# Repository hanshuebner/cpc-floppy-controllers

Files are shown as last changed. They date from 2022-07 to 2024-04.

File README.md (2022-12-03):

# Amstrad/Schneider CPC floppy controllers

> :warning: **This is a work in progress**: Don't fabricate PCBs from these files yet!

This project started as attempt to clone the Vortex F1-D floppy
controller, which supports two 720k DSDD drives.  The desire was to
have a controller that can support four drives at the same time.  The
starting point was a capture of the original PCB into a schematic,
which can be found in the [original](original/) directory.

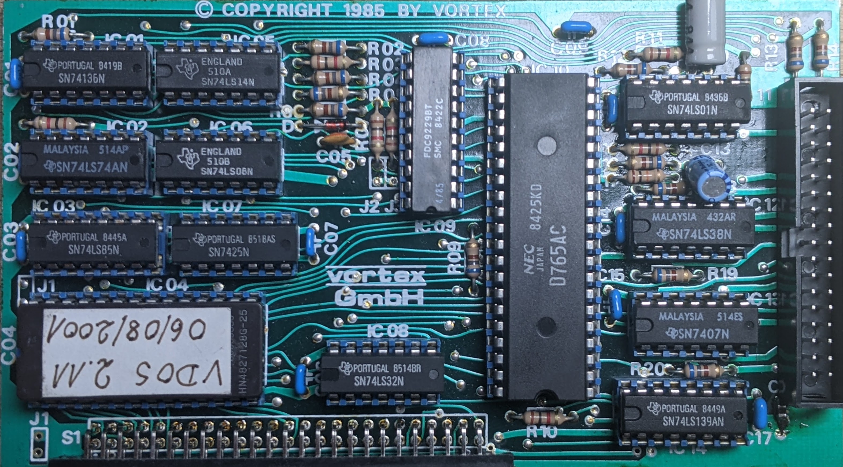
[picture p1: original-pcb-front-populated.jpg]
Vortex F1-D PCB


Multiple variants have been designed, but none of the designs in this
repository have been tested, don't fabricate any PCBs at this point!

# no-rom

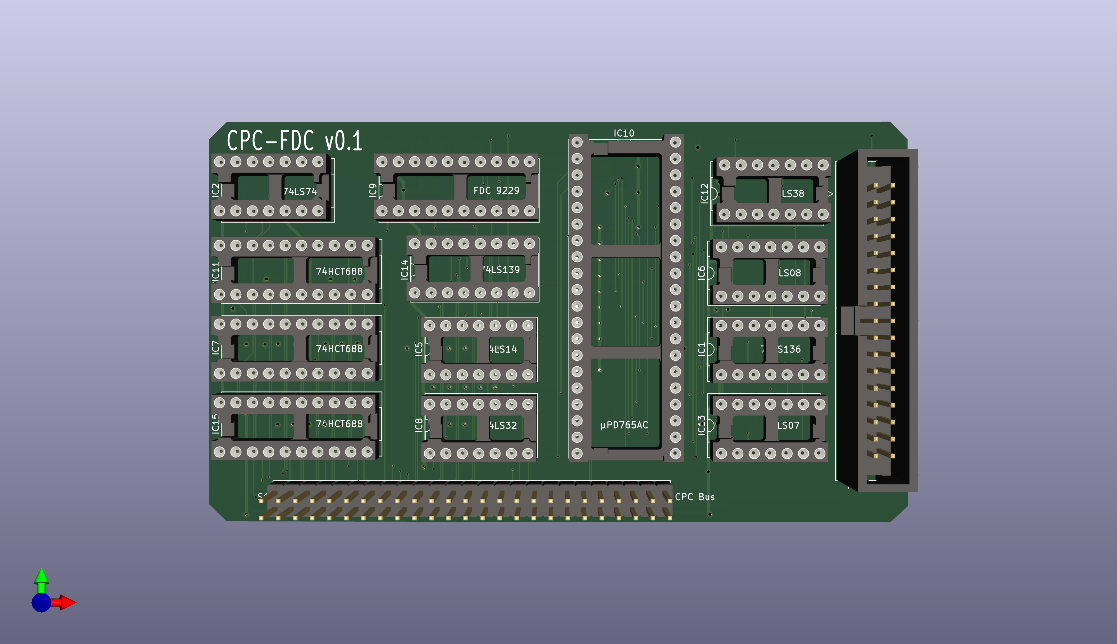
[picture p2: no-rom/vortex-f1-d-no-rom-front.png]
rendered picture of the no-rom PCB variant (front)

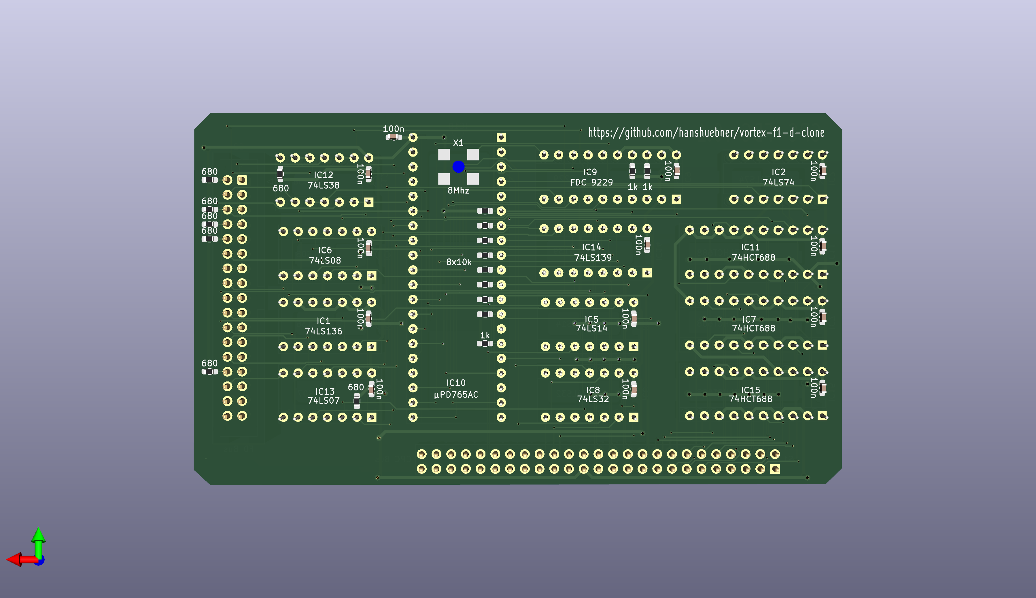
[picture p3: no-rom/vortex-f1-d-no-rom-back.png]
rendered picture of the no-rom PCB variant (back)


The [no-rom](no-rom/) variant contains a revised, but wasteful address
decoder and no ROM socket.  It works to some extent, but the first
revisions contained multiple errors and required several patches.  The
version in this repository has the fixes applied, but was not yet
fabricated and tested.

# no-rom-cpld

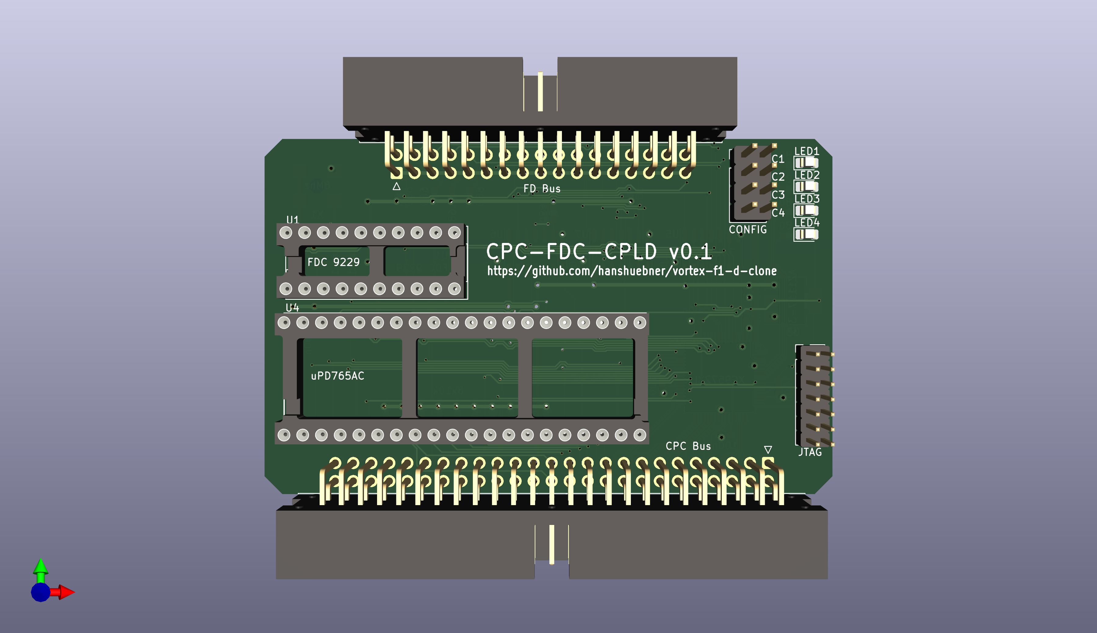
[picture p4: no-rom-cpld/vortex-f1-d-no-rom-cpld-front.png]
rendered picture of the no-rom-cpld variant (front)

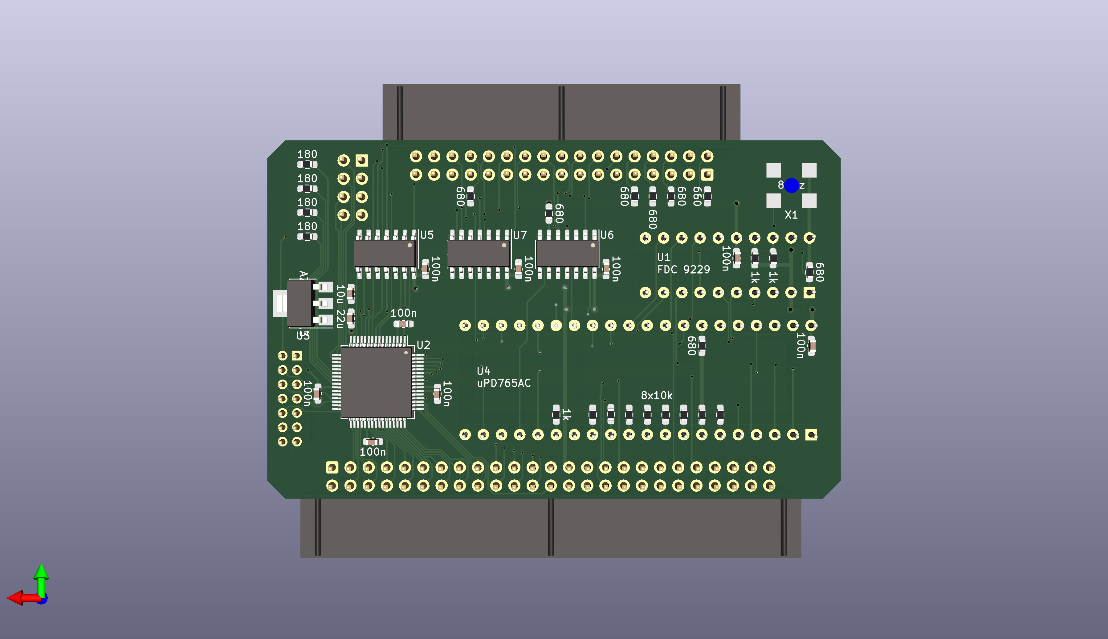
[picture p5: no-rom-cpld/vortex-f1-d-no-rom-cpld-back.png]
rendered picture of the no-rom-cpld variant (back)


The [no-rom-cpld](no-rom-cpld/) variant replaces the TTL chips with a
CPLD, reducing the part count significantly.

# rom-cpld

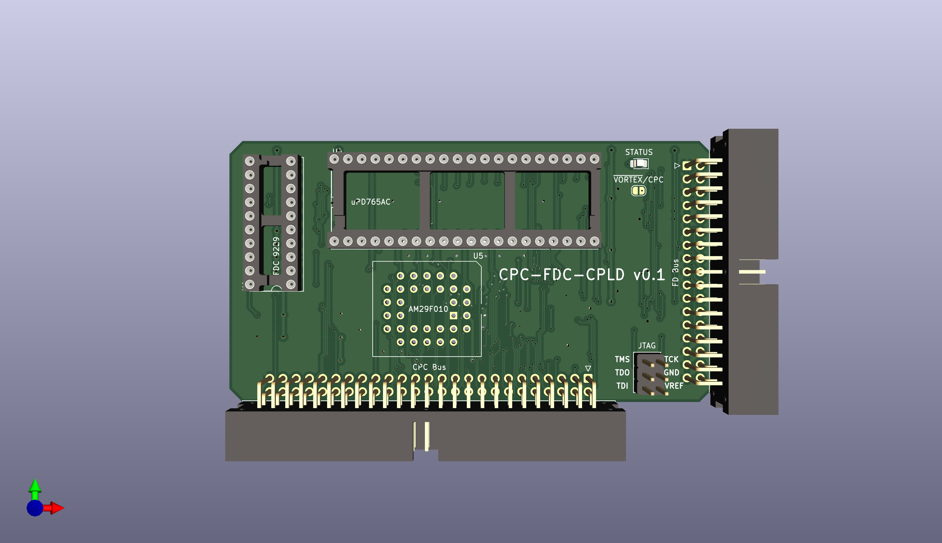
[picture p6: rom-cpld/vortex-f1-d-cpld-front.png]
rendered picture of the rom-cpld variant (front)

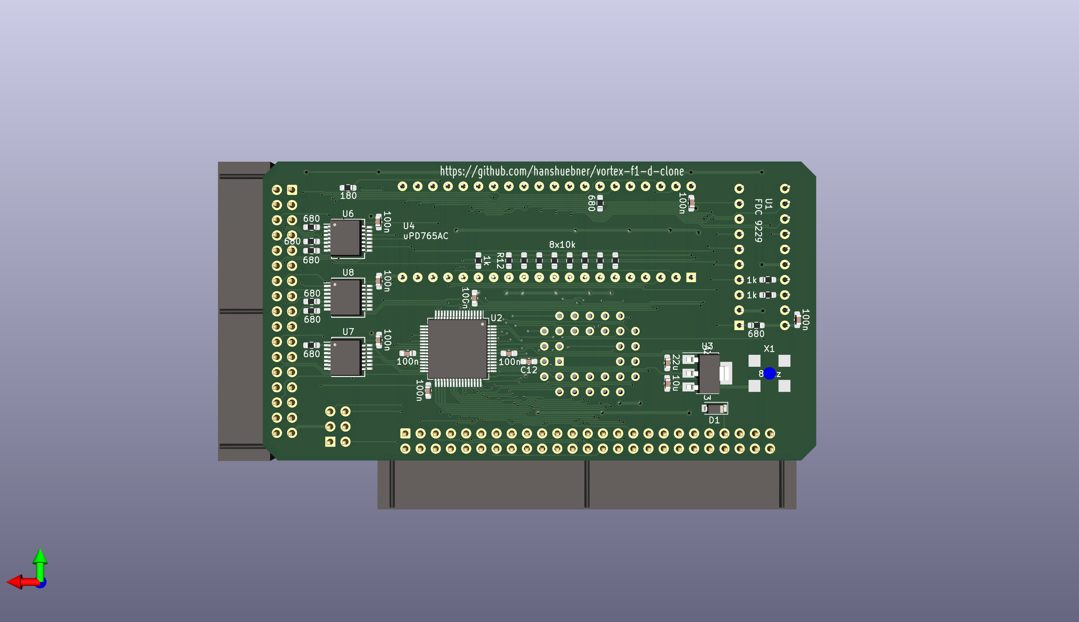
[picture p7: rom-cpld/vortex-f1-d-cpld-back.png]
rendered picture of the rom-cpld variant (back)


The [rom-cpld](rom-cpld/) variant adds a Flash ROM that can act as a universal
ROM box in addition to holding an operating system ROM to drive the
floppy disk controller.

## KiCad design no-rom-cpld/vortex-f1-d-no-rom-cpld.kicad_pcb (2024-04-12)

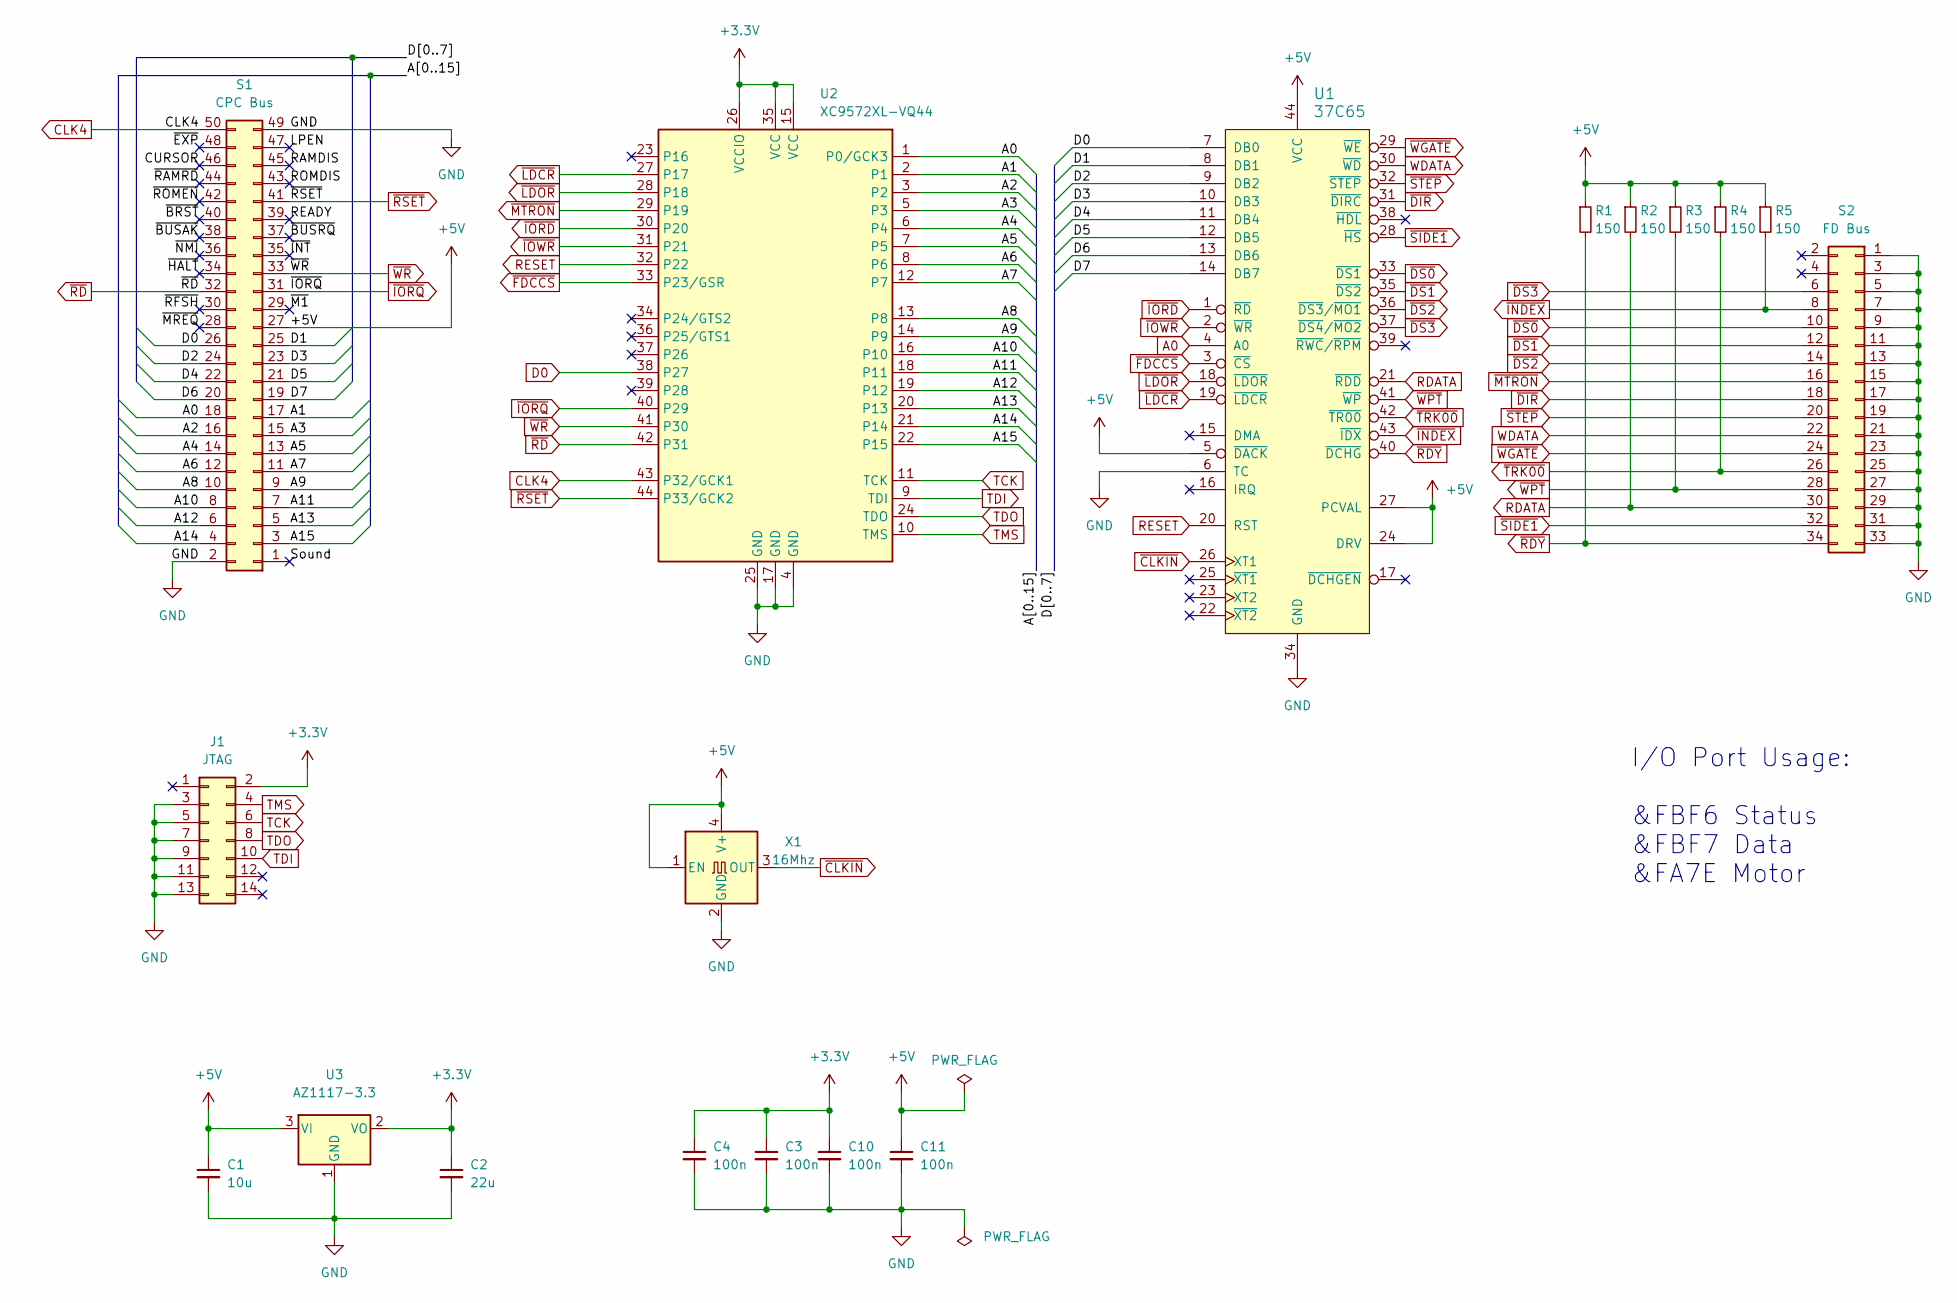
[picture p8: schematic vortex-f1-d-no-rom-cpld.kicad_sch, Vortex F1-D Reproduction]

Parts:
C1: 10u; C_0603_1608Metric_Pad1.08x0.95mm_HandSolder
C2: 22u; C_0603_1608Metric_Pad1.08x0.95mm_HandSolder
C3, C4, C10, C11: 100n; C_0603_1608Metric_Pad1.08x0.95mm_HandSolder
J1: JTAG; PinHeader_2x07_P2.00mm_Vertical
R1, R2, R3, R4, R5: 150; R_0603_1608Metric_Pad0.98x0.95mm_HandSolder
S1: CPC Bus; IDC-Header_2x25_P2.54mm_Horizontal
S2: FD Bus; IDC-Header_2x17_P2.54mm_Horizontal
U1: 37C65; PLCC-44
U2: XC9572XL-VQ44; TQFP-44_10x10mm_P0.8mm
U3: AZ1117-3.3; SOT-223-3_TabPin2
X1: 16Mhz; Oscillator_SMD_EuroQuartz_XO91-4Pin_7.0x5.0mm

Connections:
+3.3V: C2.1, C3.1, C4.1, C10.1, J1.2, U2.15 (VCC), U2.26 (VCCIO), U2.35 (VCC), U3.2 (VO)
+5V: C1.1, C11.1, R1.1, R2.1, R3.1, R4.1, R5.1, S1.27, U1.5 (~DACK), U1.24 (DRV), U1.27 (PCVAL), U1.44 (VCC), U3.3 (VI), X1.1 (EN), X1.4 (V+)
/A1: S1.17, U2.2 (P1)
/A2: S1.16, U2.3 (P2)
/A3: S1.15, U2.5 (P3)
/A4: S1.14, U2.6 (P4)
/A5: S1.13, U2.7 (P5)
/A6: S1.12, U2.8 (P6)
/A7: S1.11, U2.12 (P7)
/A8: S1.10, U2.13 (P8)
/A9: S1.9, U2.14 (P9)
/A10: S1.8, U2.16 (P10)
/A11: S1.7, U2.18 (P11)
/A12: S1.6, U2.19 (P12)
/A13: S1.5, U2.20 (P13)
/A14: S1.4, U2.21 (P14)
/A15: S1.3, U2.22 (P15)
/CURSOR: S1.46
/D1: S1.25, U1.8 (DB1)
/D2: S1.24, U1.9 (DB2)
/D3: S1.23, U1.10 (DB3)
/D4: S1.22, U1.11 (DB4)
/D5: S1.21, U1.12 (DB5)
/D6: S1.20, U1.13 (DB6)
/D7: S1.19, U1.14 (DB7)
/LPEN: S1.47
/RAMDIS: S1.45
/READY: S1.39
/ROMDIS: S1.43
/Sound: S1.1
/~BRST: S1.40
/~BUSAK: S1.38
/~BUSRQ: S1.37
/~EXP: S1.48
/~HALT: S1.34
/~INT: S1.35
/~M1: S1.29
/~MREQ: S1.28
/~NMI: S1.36
/~RAMRD: S1.44
/~RFSH: S1.30
/~ROMEN: S1.42
A0: S1.18, U1.4 (A0), U2.1 (P0/GCK3)
CLK4: S1.50, U2.43 (P32/GCK1)
D0: S1.26, U1.7 (DB0), U2.38 (P27)
GND: C1.2, C2.2, C3.2, C4.2, C10.2, C11.2, J1.3, J1.5, J1.7, J1.9, J1.11, J1.13, S1.2, S1.49, S2.1, S2.3, S2.5, S2.7, S2.9, S2.11, S2.13, S2.15, S2.17, S2.19, S2.21, S2.23, S2.25, S2.27, S2.29, S2.31, S2.33, U1.6 (TC), U1.34 (GND), U2.4 (GND), U2.17 (GND), U2.25 (GND), U3.1 (GND), X1.2 (GND)
RDATA: R2.2, S2.30, U1.21 (~RDD)
RESET: U1.20 (RST), U2.32 (P22)
TCK: J1.6, U2.11 (TCK)
TDI: J1.10, U2.9 (TDI)
TDO: J1.8, U2.24 (TDO)
TMS: J1.4, U2.10 (TMS)
WDATA: S2.22, U1.30 (~WD)
~CLKIN: U1.26 (XT1), X1.3 (OUT)
~DIR: S2.18, U1.31 (~DIRC)
~DS0: S2.10, U1.33 (~DS1)
~DS1: S2.12, U1.35 (~DS2)
~DS2: S2.14, U1.36 (~DS3/~MO1)
~DS3: S2.6, U1.37 (~DS4/~MO2)
~FDCCS: U1.3 (~CS), U2.33 (P23/GSR)
~INDEX: R5.2, S2.8, U1.43 (~IDX)
~IORD: U1.1 (~RD), U2.30 (P20)
~IORQ: S1.31, U2.40 (P29)
~IOWR: U1.2 (~WR), U2.31 (P21)
~LDCR: U1.19 (~LDCR), U2.27 (P17)
~LDOR: U1.18 (~LDOR), U2.28 (P18)
~RDY: R1.2, S2.34, U1.40 (~DCHG)
~RD: S1.32, U2.42 (P31)
~RSET: S1.41, U2.44 (P33/GCK2)
~SIDE1: S2.32, U1.28 (~HS)
~STEP: S2.20, U1.32 (~STEP)
~TRK00: R4.2, S2.26, U1.42 (~TR00)
~WGATE: S2.24, U1.29 (~WE)
~WPT: R3.2, S2.28, U1.41 (~WP)
~WR: S1.33, U2.41 (P30)

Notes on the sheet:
I/O Port Usage: &FBF6 Status &FBF7 Data &FA7E Motor

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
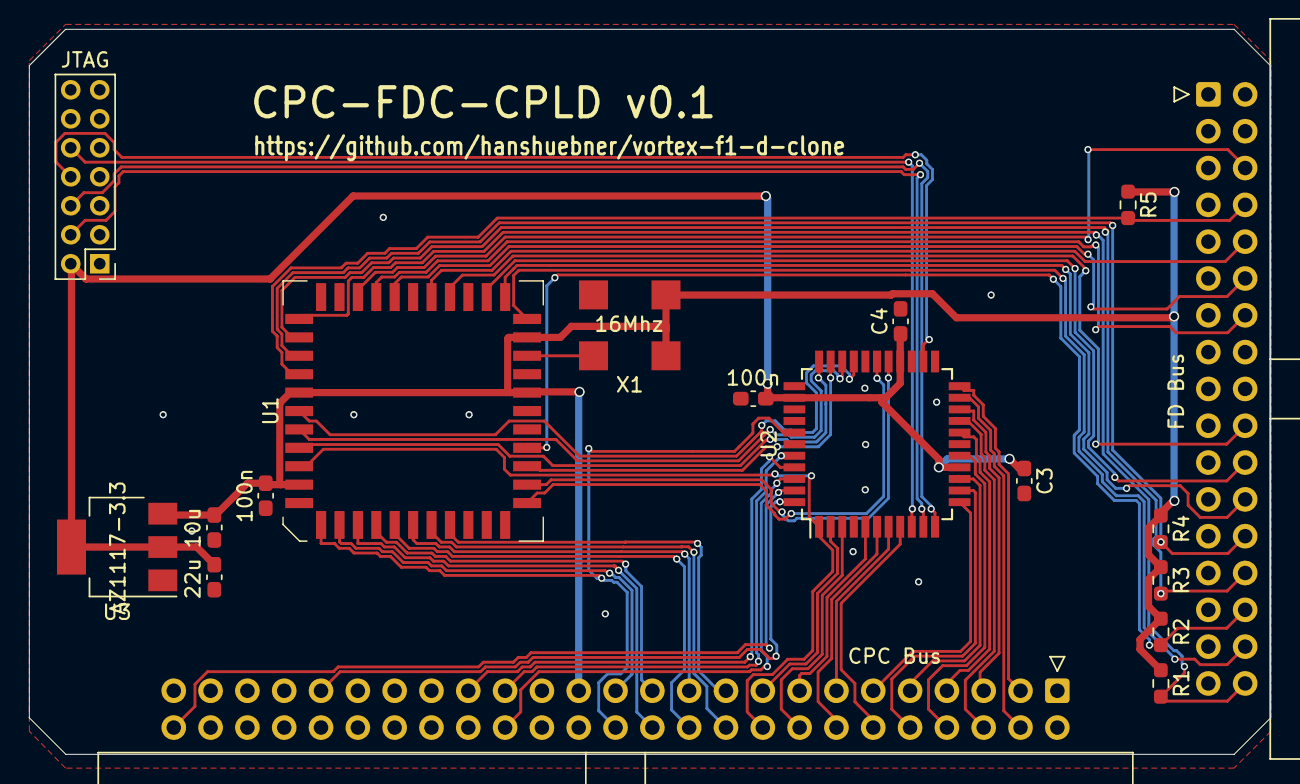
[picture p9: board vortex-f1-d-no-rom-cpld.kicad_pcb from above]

Board: 2 copper layers, 85.6 x 50.0 mm, 18 parts (0 on the bottom side), 57 nets.

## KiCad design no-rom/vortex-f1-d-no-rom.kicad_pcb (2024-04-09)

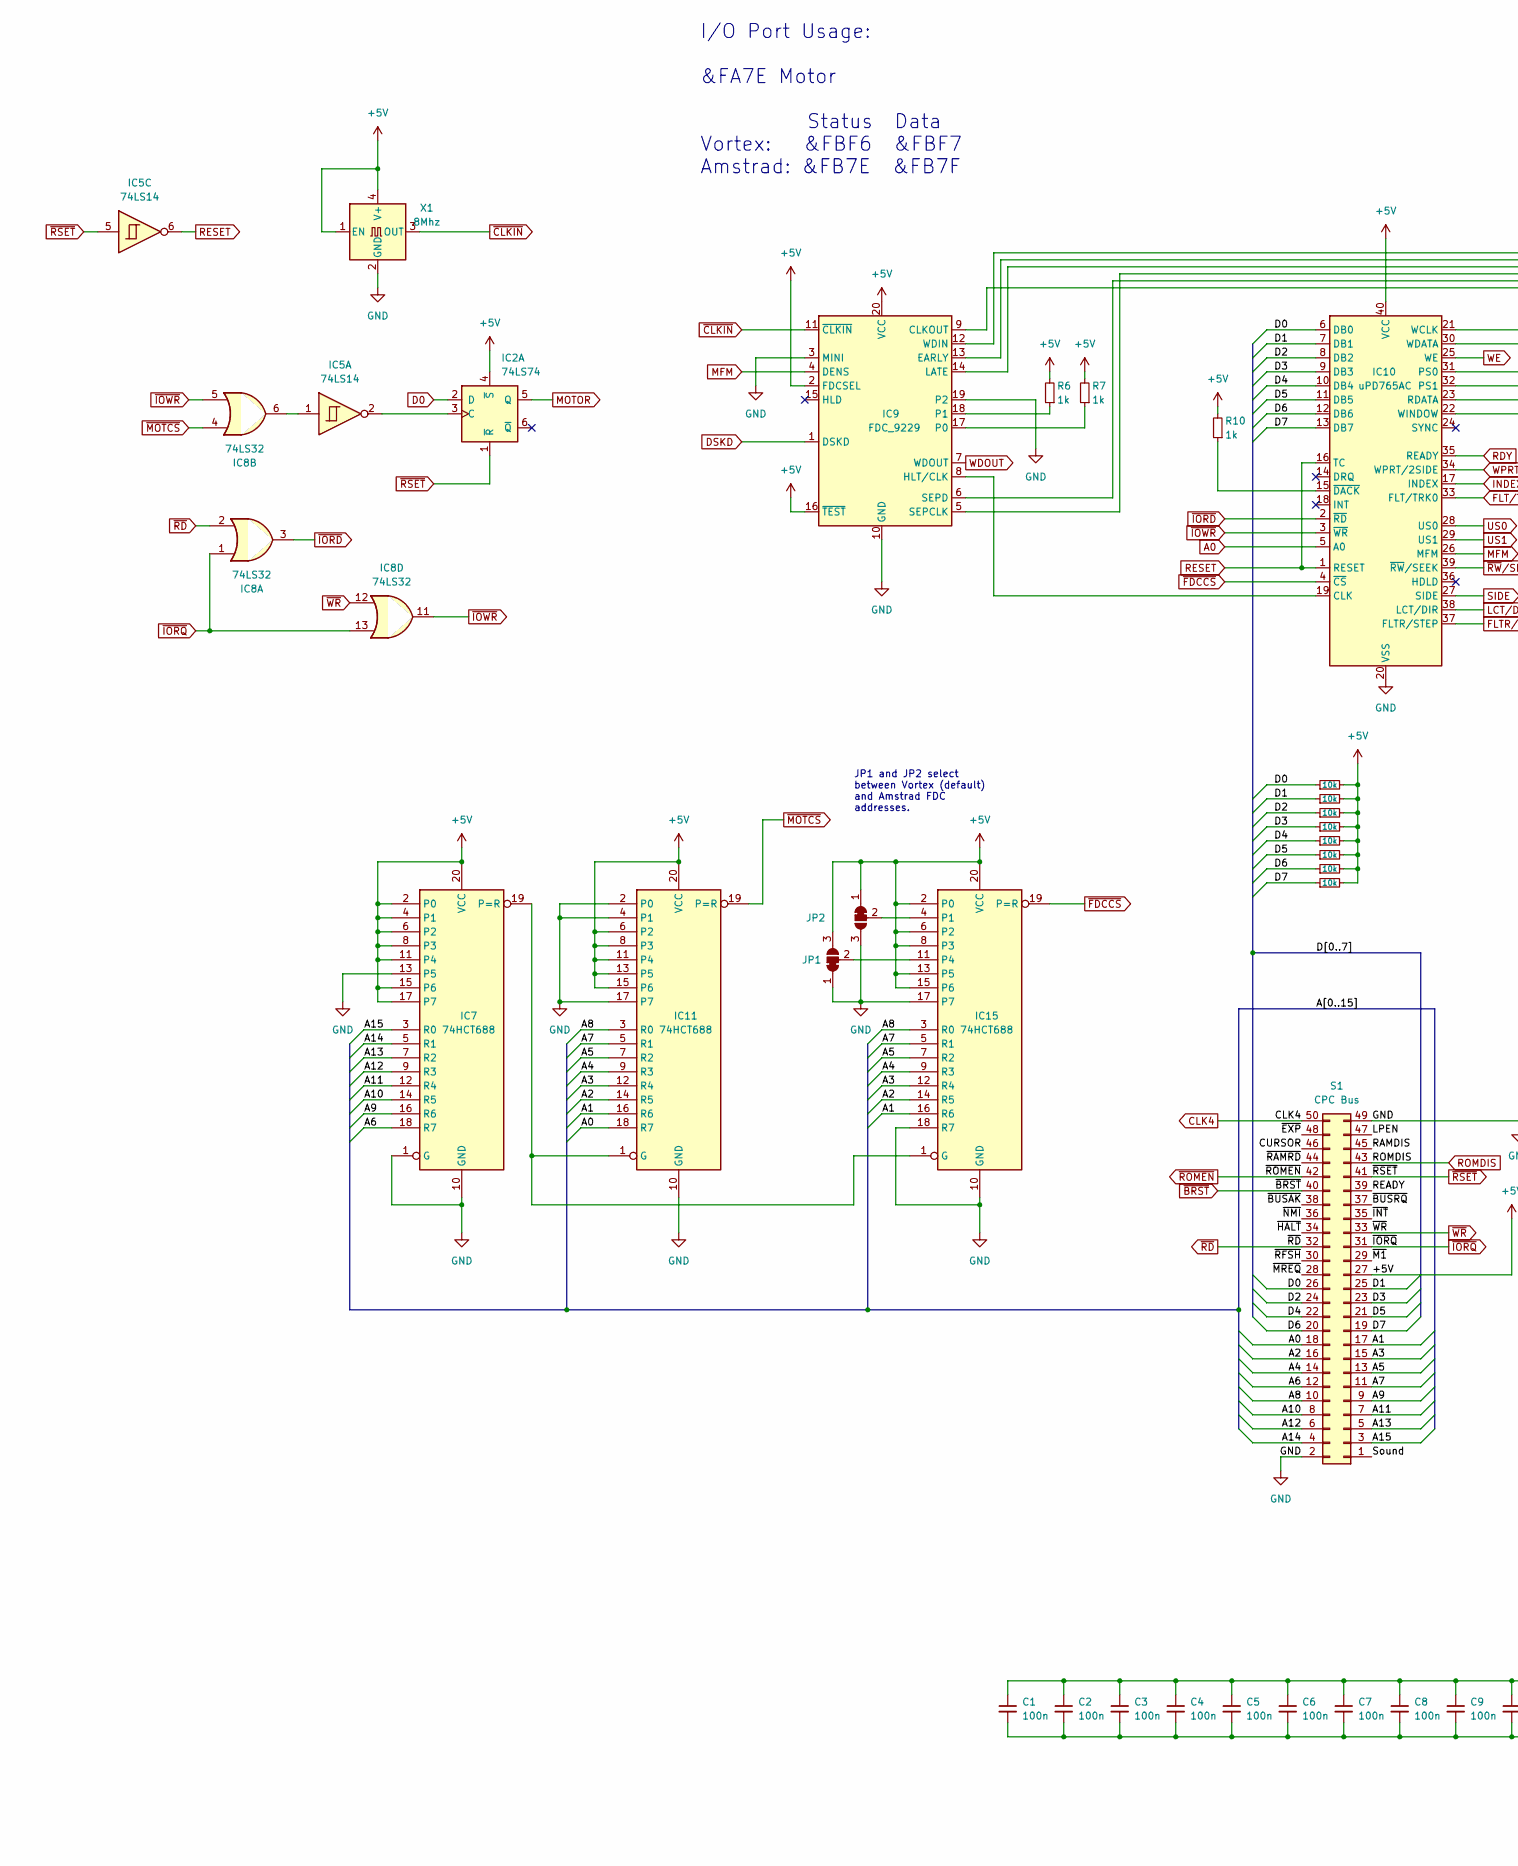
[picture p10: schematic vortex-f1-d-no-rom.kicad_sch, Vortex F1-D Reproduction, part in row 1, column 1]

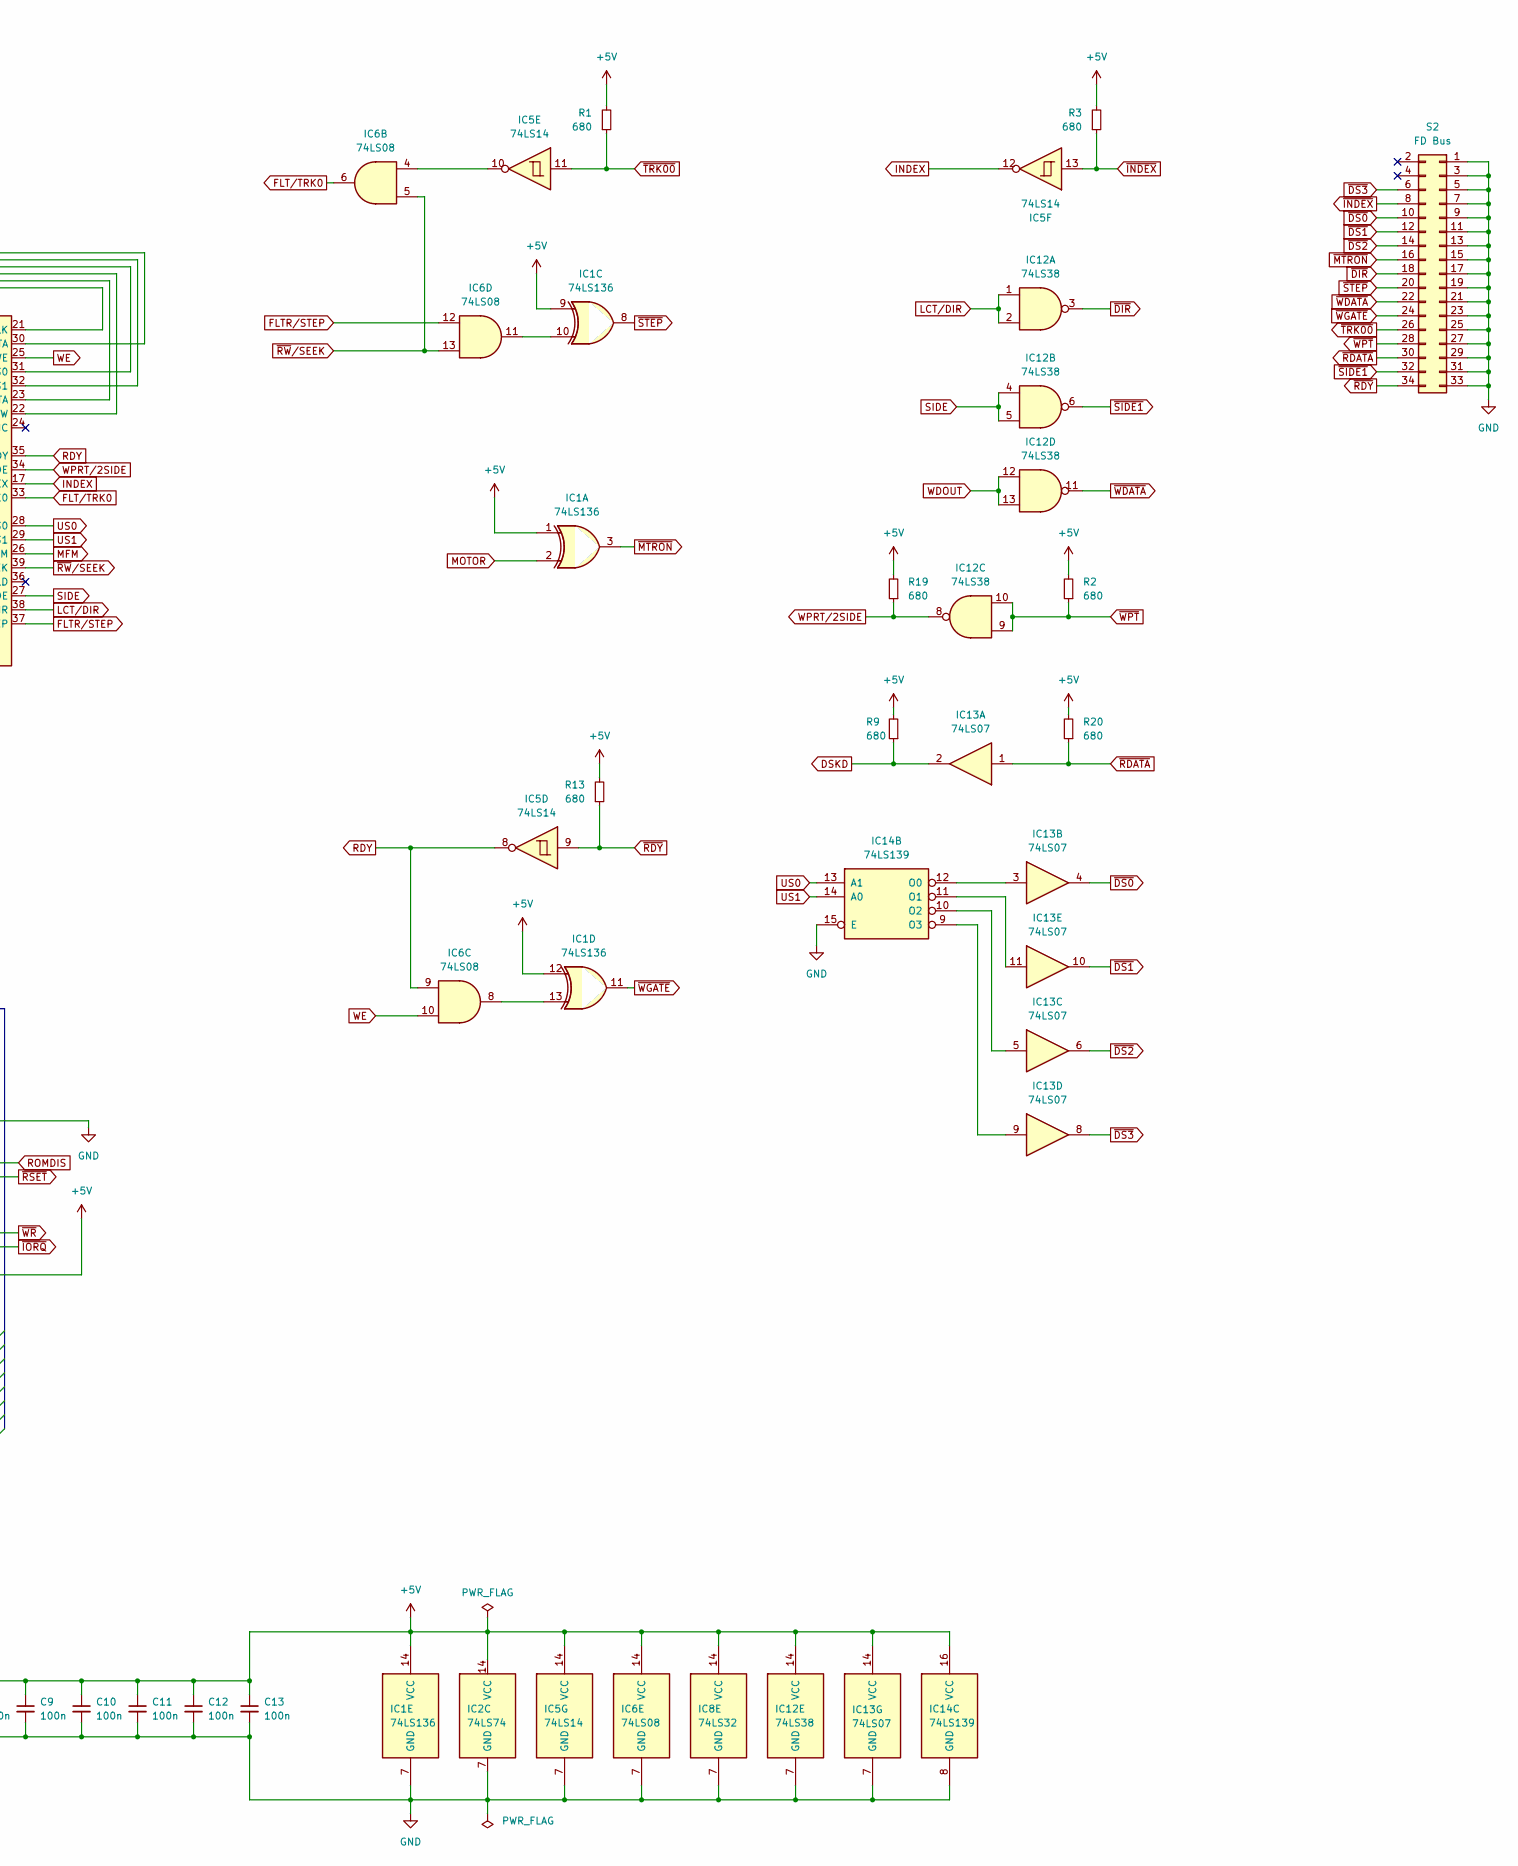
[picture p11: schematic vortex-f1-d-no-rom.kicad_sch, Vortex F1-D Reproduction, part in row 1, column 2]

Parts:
C1, C2, C3, C4, C5, C6, C7, C8, C9, C10, C11, C12, C13: 100n; C_0603_1608Metric_Pad1.08x0.95mm_HandSolder
IC1: 74LS136; DIP-14_W7.62mm_Socket
IC2: 74LS74; DIP-14_W7.62mm_Socket
IC5: 74LS14; DIP-14_W7.62mm_Socket
IC6: 74LS08; DIP-14_W7.62mm_Socket
IC7, IC11, IC15: 74HCT688; DIP-20_W7.62mm_Socket
IC8: 74LS32; DIP-14_W7.62mm_Socket
IC9: FDC_9229; DIP-20_W7.62mm_Socket
IC10: uPD765AC; DIP-40_W15.24mm_Socket
IC12: 74LS38; DIP-14_W7.62mm_Socket
IC13: 74LS07; DIP-14_W7.62mm_Socket
IC14: 74LS139; DIP-16_W7.62mm_Socket
JP1: SolderJumper-3_P1.3mm_Bridged12_RoundedPad1.0x1.5mm
JP2: SolderJumper_3_Bridged12; SolderJumper-3_P1.3mm_Bridged12_RoundedPad1.0x1.5mm
R1, R2, R3, R9, R13, R19, R20: 680; R_0603_1608Metric_Pad0.98x0.95mm_HandSolder
R6, R7, R10: 1k; R_0603_1608Metric_Pad0.98x0.95mm_HandSolder
R8, R14, R17, R18, R23, R24, R25, R26: 10k; R_0603_1608Metric_Pad0.98x0.95mm_HandSolder
S1: CPC Bus; PinHeader_2x25_P2.54mm_Vertical
S2: FD Bus; IDC-Header_2x17_P2.54mm_Vertical
X1: 8Mhz; Oscillator_SMD_EuroQuartz_XO91-4Pin_7.0x5.0mm

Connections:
+5V: C1.1, C2.1, C3.1, C4.1, C5.1, C6.1, C7.1, C8.1, C9.1, C10.1, C11.1, C12.1, C13.1, IC1.1, IC1.9, IC1.12, IC1.14 (VCC), IC2.4 (~S), IC2.14 (VCC), IC5.14 (VCC), IC6.14 (VCC), IC7.2 (P0), IC7.4 (P1), IC7.6 (P2), IC7.8 (P3), IC7.11 (P4), IC7.15 (P6), IC7.17 (P7), IC7.20 (VCC), IC8.14 (VCC), IC9.2 (FDCSEL), IC9.16 (~TEST), IC9.20 (VCC), IC10.40 (VCC), IC11.6 (P2), IC11.8 (P3), IC11.11 (P4), IC11.13 (P5), IC11.15 (P6), IC11.20 (VCC), IC12.14 (VCC), IC13.14 (VCC), IC14.16 (VCC), IC15.2 (P0), IC15.6 (P2), IC15.8 (P3), IC15.13 (P5), IC15.15 (P6), IC15.20 (VCC), JP1.3 (B), JP2.1 (A), R1.2, R2.2, R3.2, R6.2, R7.2, R8.2, R9.2, R10.2, R13.2, R14.2, R17.2, R18.2, R19.2, R20.2, R23.2, R24.2, R25.2, R26.2, S1.27, X1.1 (EN), X1.4 (V+)
/A1: IC11.16 (R6), IC15.16 (R6), S1.17
/A2: IC11.14 (R5), IC15.14 (R5), S1.16
/A3: IC11.12 (R4), IC15.12 (R4), S1.15
/A4: IC11.9 (R3), IC15.9 (R3), S1.14
/A5: IC11.7 (R2), IC15.7 (R2), S1.13
/A6: IC7.18 (R7), S1.12
/A7: IC11.5 (R1), IC15.5 (R1), S1.11
/A8: IC11.3 (R0), IC15.3 (R0), S1.10
/A9: IC7.16 (R6), S1.9
/A10: IC7.14 (R5), S1.8
/A11: IC7.12 (R4), S1.7
/A12: IC7.9 (R3), S1.6
/A13: IC7.7 (R2), S1.5
/A14: IC7.5 (R1), S1.4
/A15: IC7.3 (R0), S1.3
/CURSOR: S1.46
/D1: IC10.7 (DB1), R14.1, S1.25
/D2: IC10.8 (DB2), R17.1, S1.24
/D3: IC10.9 (DB3), R18.1, S1.23
/D4: IC10.10 (DB4), R23.1, S1.22
/D5: IC10.11 (DB5), R24.1, S1.21
/D6: IC10.12 (DB6), R25.1, S1.20
/D7: IC10.13 (DB7), R26.1, S1.19
/LPEN: S1.47
/RAMDIS: S1.45
/READY: S1.39
/Sound: S1.1
/~BUSAK: S1.38
/~BUSRQ: S1.37
/~EXP: S1.48
/~HALT: S1.34
/~INT: S1.35
/~M1: S1.29
/~MREQ: S1.28
/~NMI: S1.36
/~RAMRD: S1.44
/~RFSH: S1.30
A0: IC10.5 (A0), IC11.18 (R7), S1.18
CLK4: S1.50
D0: IC2.2 (D), IC10.6 (DB0), R8.1, S1.26
DSKD: IC9.1 (DSKD), IC13.2, R9.1
FLTR/STEP: IC6.12, IC10.37 (FLTR/STEP)
FLT/TRK0: IC6.6, IC10.33 (FLT/TRK0)
GND: C1.2, C2.2, C3.2, C4.2, C5.2, C6.2, C7.2, C8.2, C9.2, C10.2, C11.2, C12.2, C13.2, IC1.7 (GND), IC2.7 (GND), IC5.7 (GND), IC6.7 (GND), IC7.1 (G), IC7.10 (GND), IC7.13 (P5), IC8.7 (GND), IC9.3 (MINI), IC9.10 (GND), IC9.19 (P2), IC10.20 (VSS), IC11.2 (P0), IC11.4 (P1), IC11.10 (GND), IC11.17 (P7), IC12.7 (GND), IC13.7 (GND), IC14.8 (GND), IC14.15 (E), IC15.10 (GND), IC15.17 (P7), IC15.18 (R7), JP1.1 (A), JP2.3 (B), S1.2, S1.49, S2.1, S2.3, S2.5, S2.7, S2.9, S2.11, S2.13, S2.15, S2.17, S2.19, S2.21, S2.23, S2.25, S2.27, S2.29, S2.31, S2.33, X1.2 (GND)
INDEX: IC5.12, IC10.17 (INDEX)
LCT/DIR: IC10.38 (LCT/DIR), IC12.1, IC12.2
MFM: IC9.4 (DENS), IC10.26 (MFM)
MOTOR: IC1.2, IC2.5 (Q)
unnamed: IC1.10, IC6.11
unnamed: IC1.13, IC6.8
unnamed: IC2.3 (C), IC5.2
unnamed: IC5.1, IC8.6
unnamed: IC5.10, IC6.4
unnamed: IC9.17 (P0), R7.1
unnamed: IC9.18 (P1), R6.1
unnamed: IC9.8 (HLT/CLK), IC10.19 (CLK)
unnamed: IC9.14 (LATE), IC10.31 (PS0)
unnamed: IC9.13 (EARLY), IC10.32 (PS1)
unnamed: IC9.6 (SEPD), IC10.23 (RDATA)
unnamed: IC9.9 (CLKOUT), IC10.21 (WCLK)
unnamed: IC9.12 (WDIN), IC10.30 (WDATA)
unnamed: IC9.5 (SEPCLK), IC10.22 (WINDOW)
unnamed: IC10.15 (~DACK), R10.1
unnamed: IC7.19 (P=R), IC11.1 (G), IC15.1 (G)
unnamed: IC13.3, IC14.12 (O0)
unnamed: IC13.11, IC14.11 (O1)
unnamed: IC13.5, IC14.10 (O2)
unnamed: IC13.9, IC14.9 (O3)
unnamed: IC15.4 (P1), JP2.2 (C)
unnamed: IC15.11 (P4), JP1.2 (C)
RDY: IC5.8, IC6.9, IC10.35 (READY)
RESET: IC5.6, IC10.1 (RESET), IC10.16 (TC)
ROMDIS: S1.43
SIDE: IC10.27 (SIDE), IC12.4, IC12.5
US0: IC10.28 (US0), IC14.13 (A1)
US1: IC10.29 (US1), IC14.14 (A0)
WDOUT: IC9.7 (WDOUT), IC12.12, IC12.13
WE: IC6.10, IC10.25 (WE)
WPRT/2SIDE: IC10.34 (WPRT/2SIDE), IC12.8, R19.1
~BRST: S1.40
~CLKIN: IC9.11 (~CLKIN), X1.3 (OUT)
~DIR: IC12.3, S2.18
~DS0: IC13.4, S2.10
~DS1: IC13.10, S2.12
~DS2: IC13.6, S2.14
~DS3: IC13.8, S2.6
~FDCCS: IC10.4 (~CS), IC15.19 (P=R)
~INDEX: IC5.13, R3.1, S2.8
~IORD: IC8.3, IC10.2 (~RD)
~IORQ: IC8.1, IC8.13, S1.31
~IOWR: IC8.5, IC8.11, IC10.3 (~WR)
~MOTCS: IC8.4, IC11.19 (P=R)
~MTRON: IC1.3, S2.16
~RDATA: IC13.1, R20.1, S2.30
~RDY: IC5.9, R13.1, S2.34
~RD: IC8.2, S1.32
~ROMEN: S1.42
~RSET: IC2.1 (~R), IC5.5, S1.41
~RW/SEEK: IC6.5, IC6.13, IC10.39 (~RW/SEEK)
~SIDE1: IC12.6, S2.32
~STEP: IC1.8, S2.20
~TRK00: IC5.11, R1.1, S2.26
~WDATA: IC12.11, S2.22
~WGATE: IC1.11, S2.24
~WPT: IC12.9, IC12.10, R2.1, S2.28
~WR: IC8.12, S1.33

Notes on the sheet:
JP1 and JP2 select between Vortex (default) and Amstrad FDC addresses.
I/O Port Usage: &FA7E Motor Status Data Vortex: &FBF6 &FBF7 Amstrad: &FB7E &FB7F

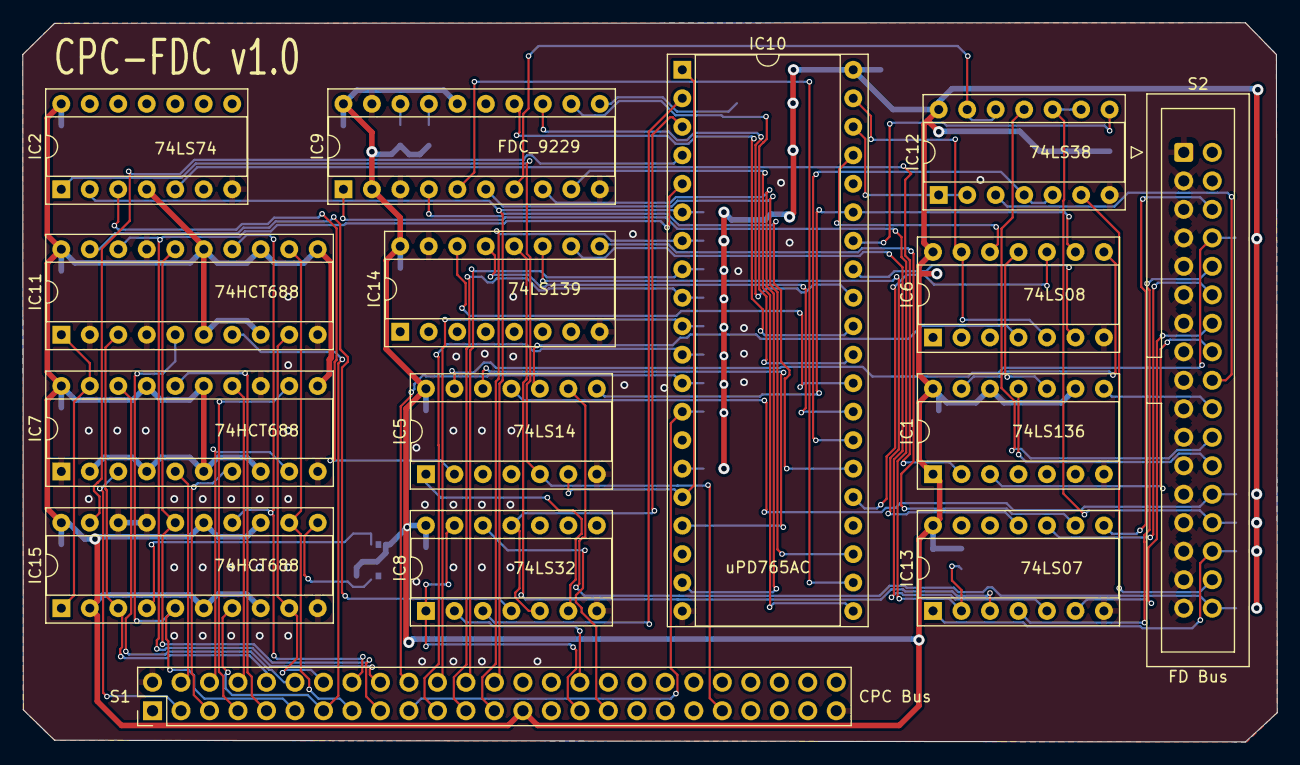
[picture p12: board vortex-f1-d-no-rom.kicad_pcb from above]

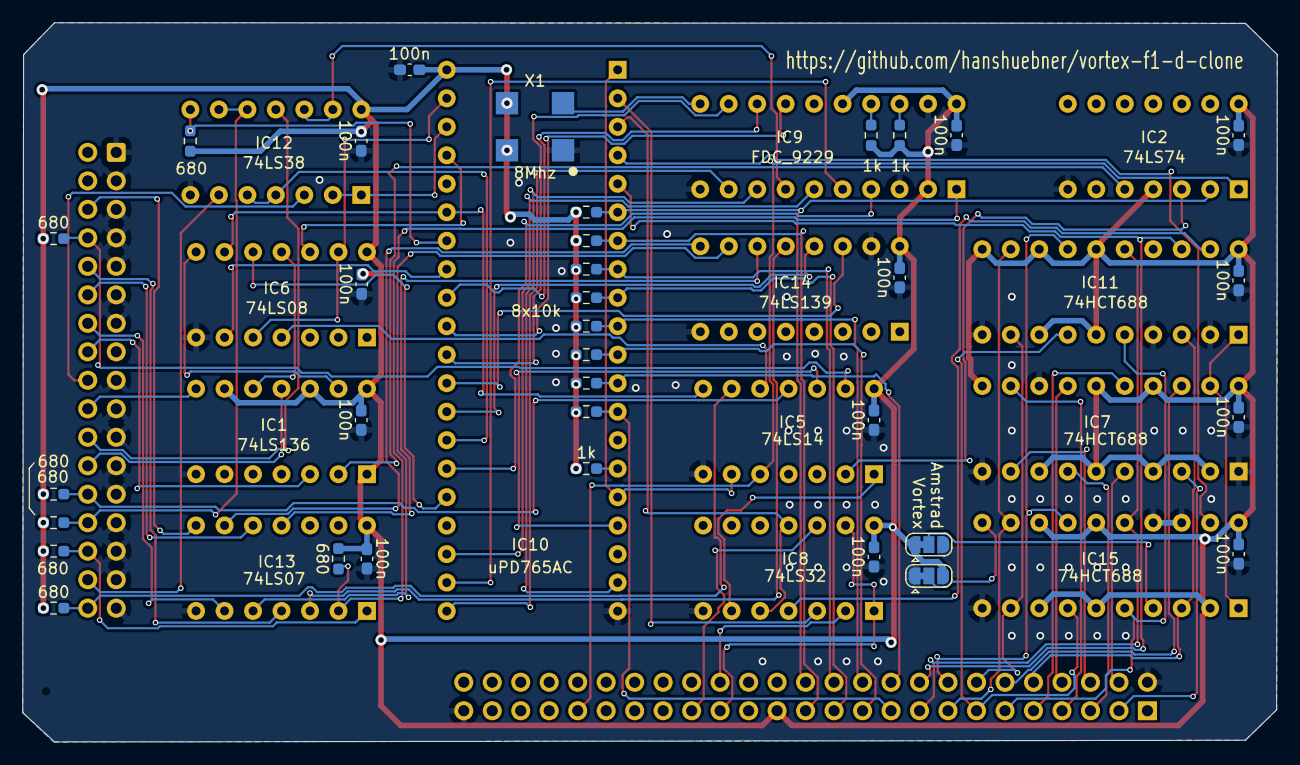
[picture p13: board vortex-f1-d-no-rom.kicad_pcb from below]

Board: 2 copper layers, 111.9 x 64.1 mm, 49 parts (34 on the bottom side), 88 nets.

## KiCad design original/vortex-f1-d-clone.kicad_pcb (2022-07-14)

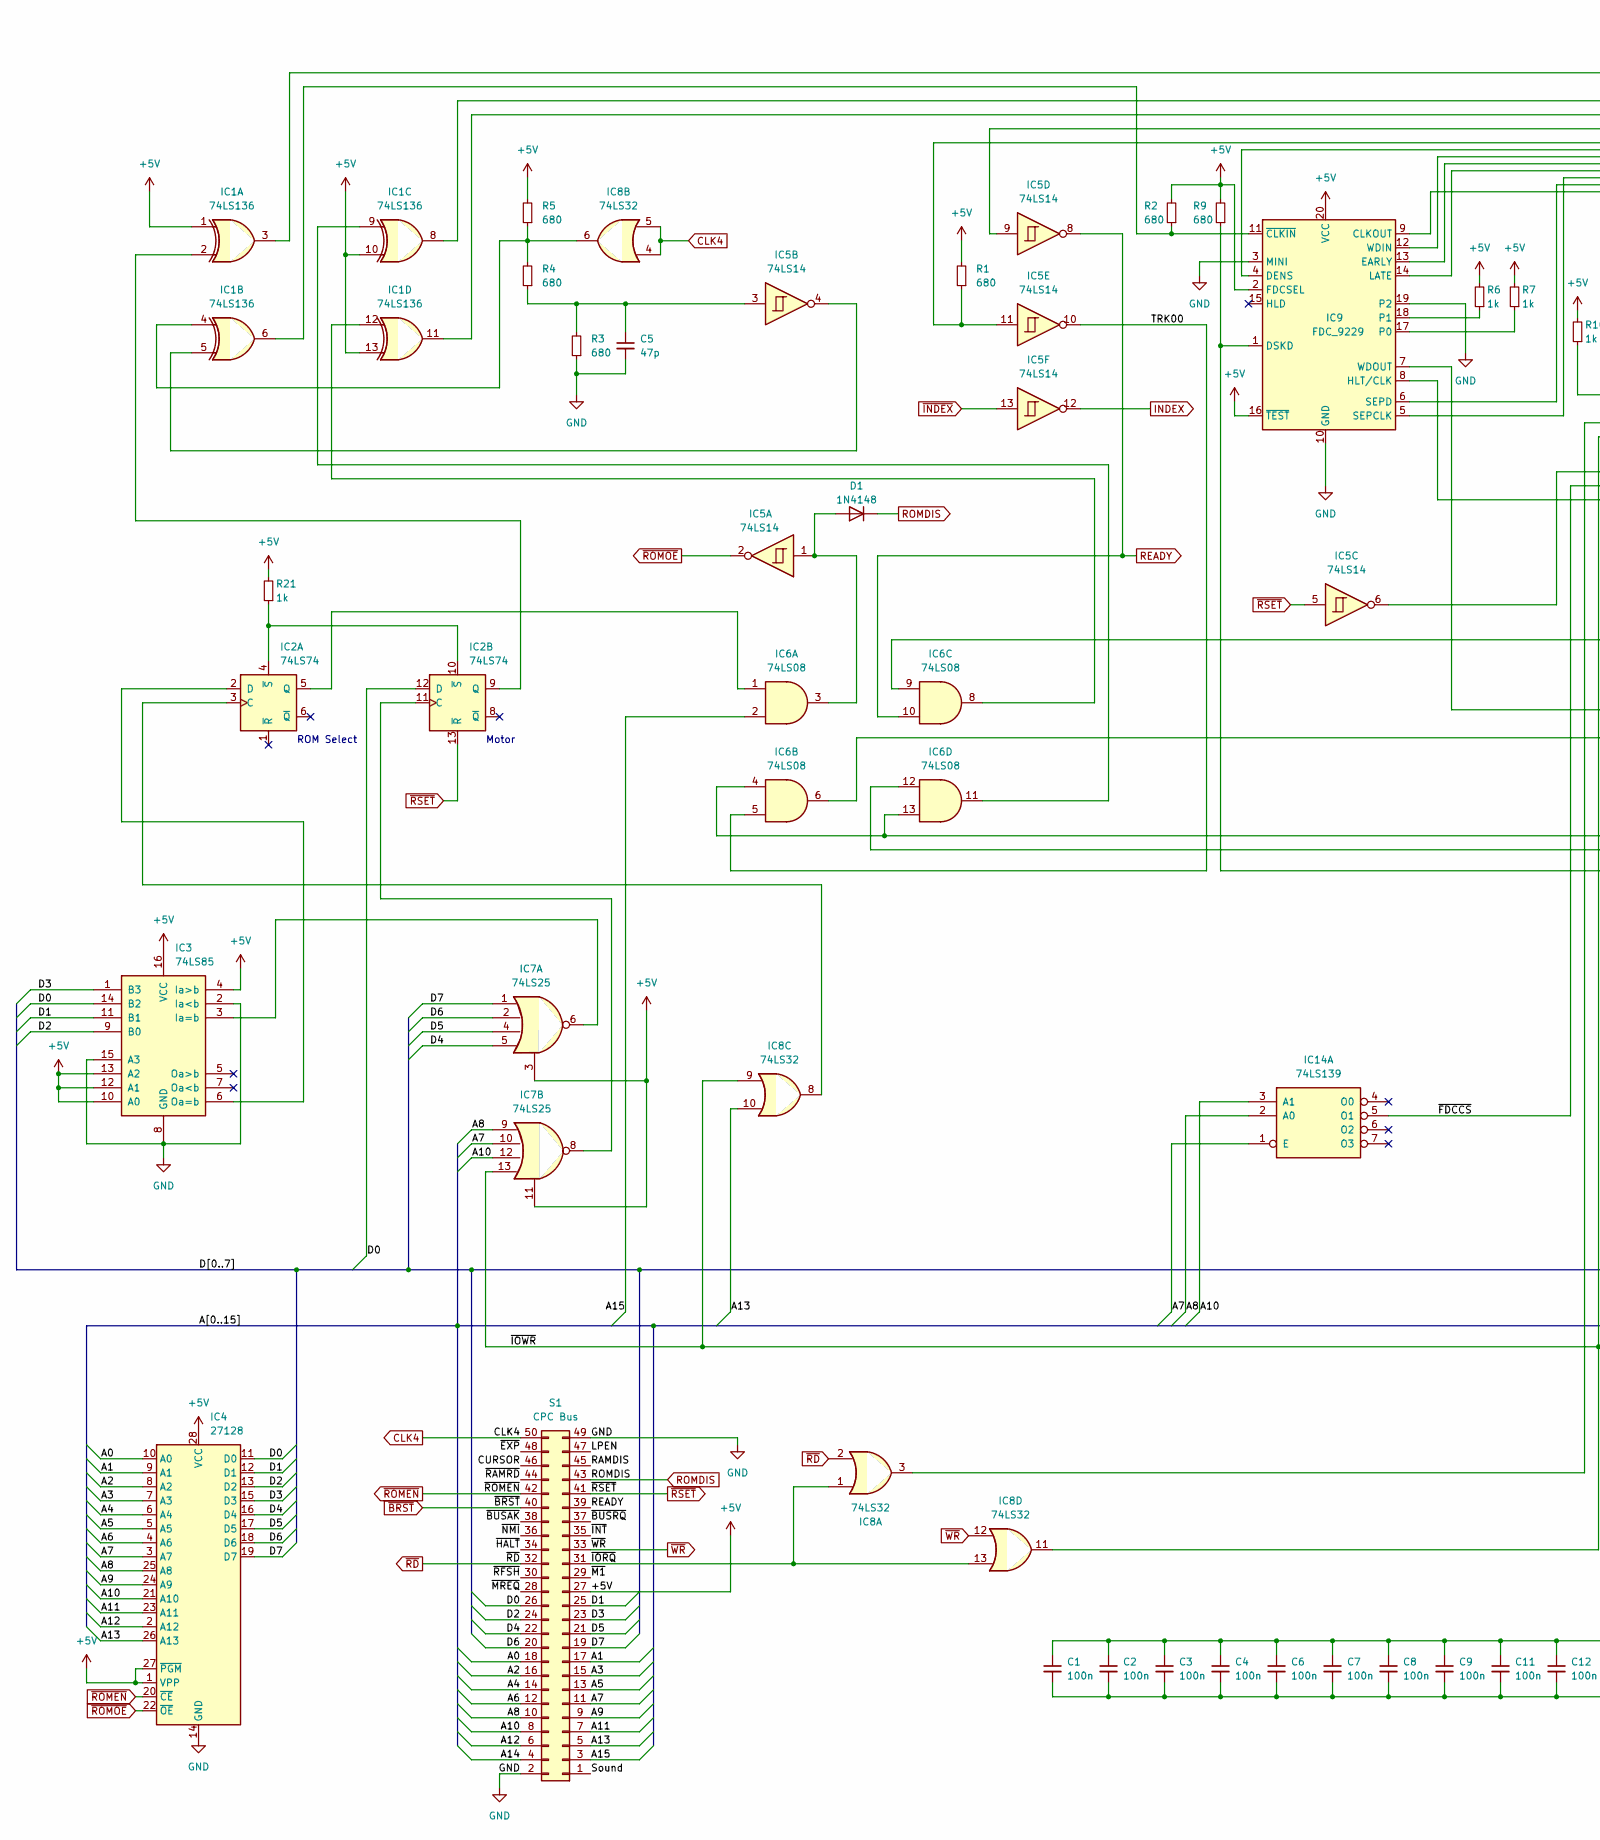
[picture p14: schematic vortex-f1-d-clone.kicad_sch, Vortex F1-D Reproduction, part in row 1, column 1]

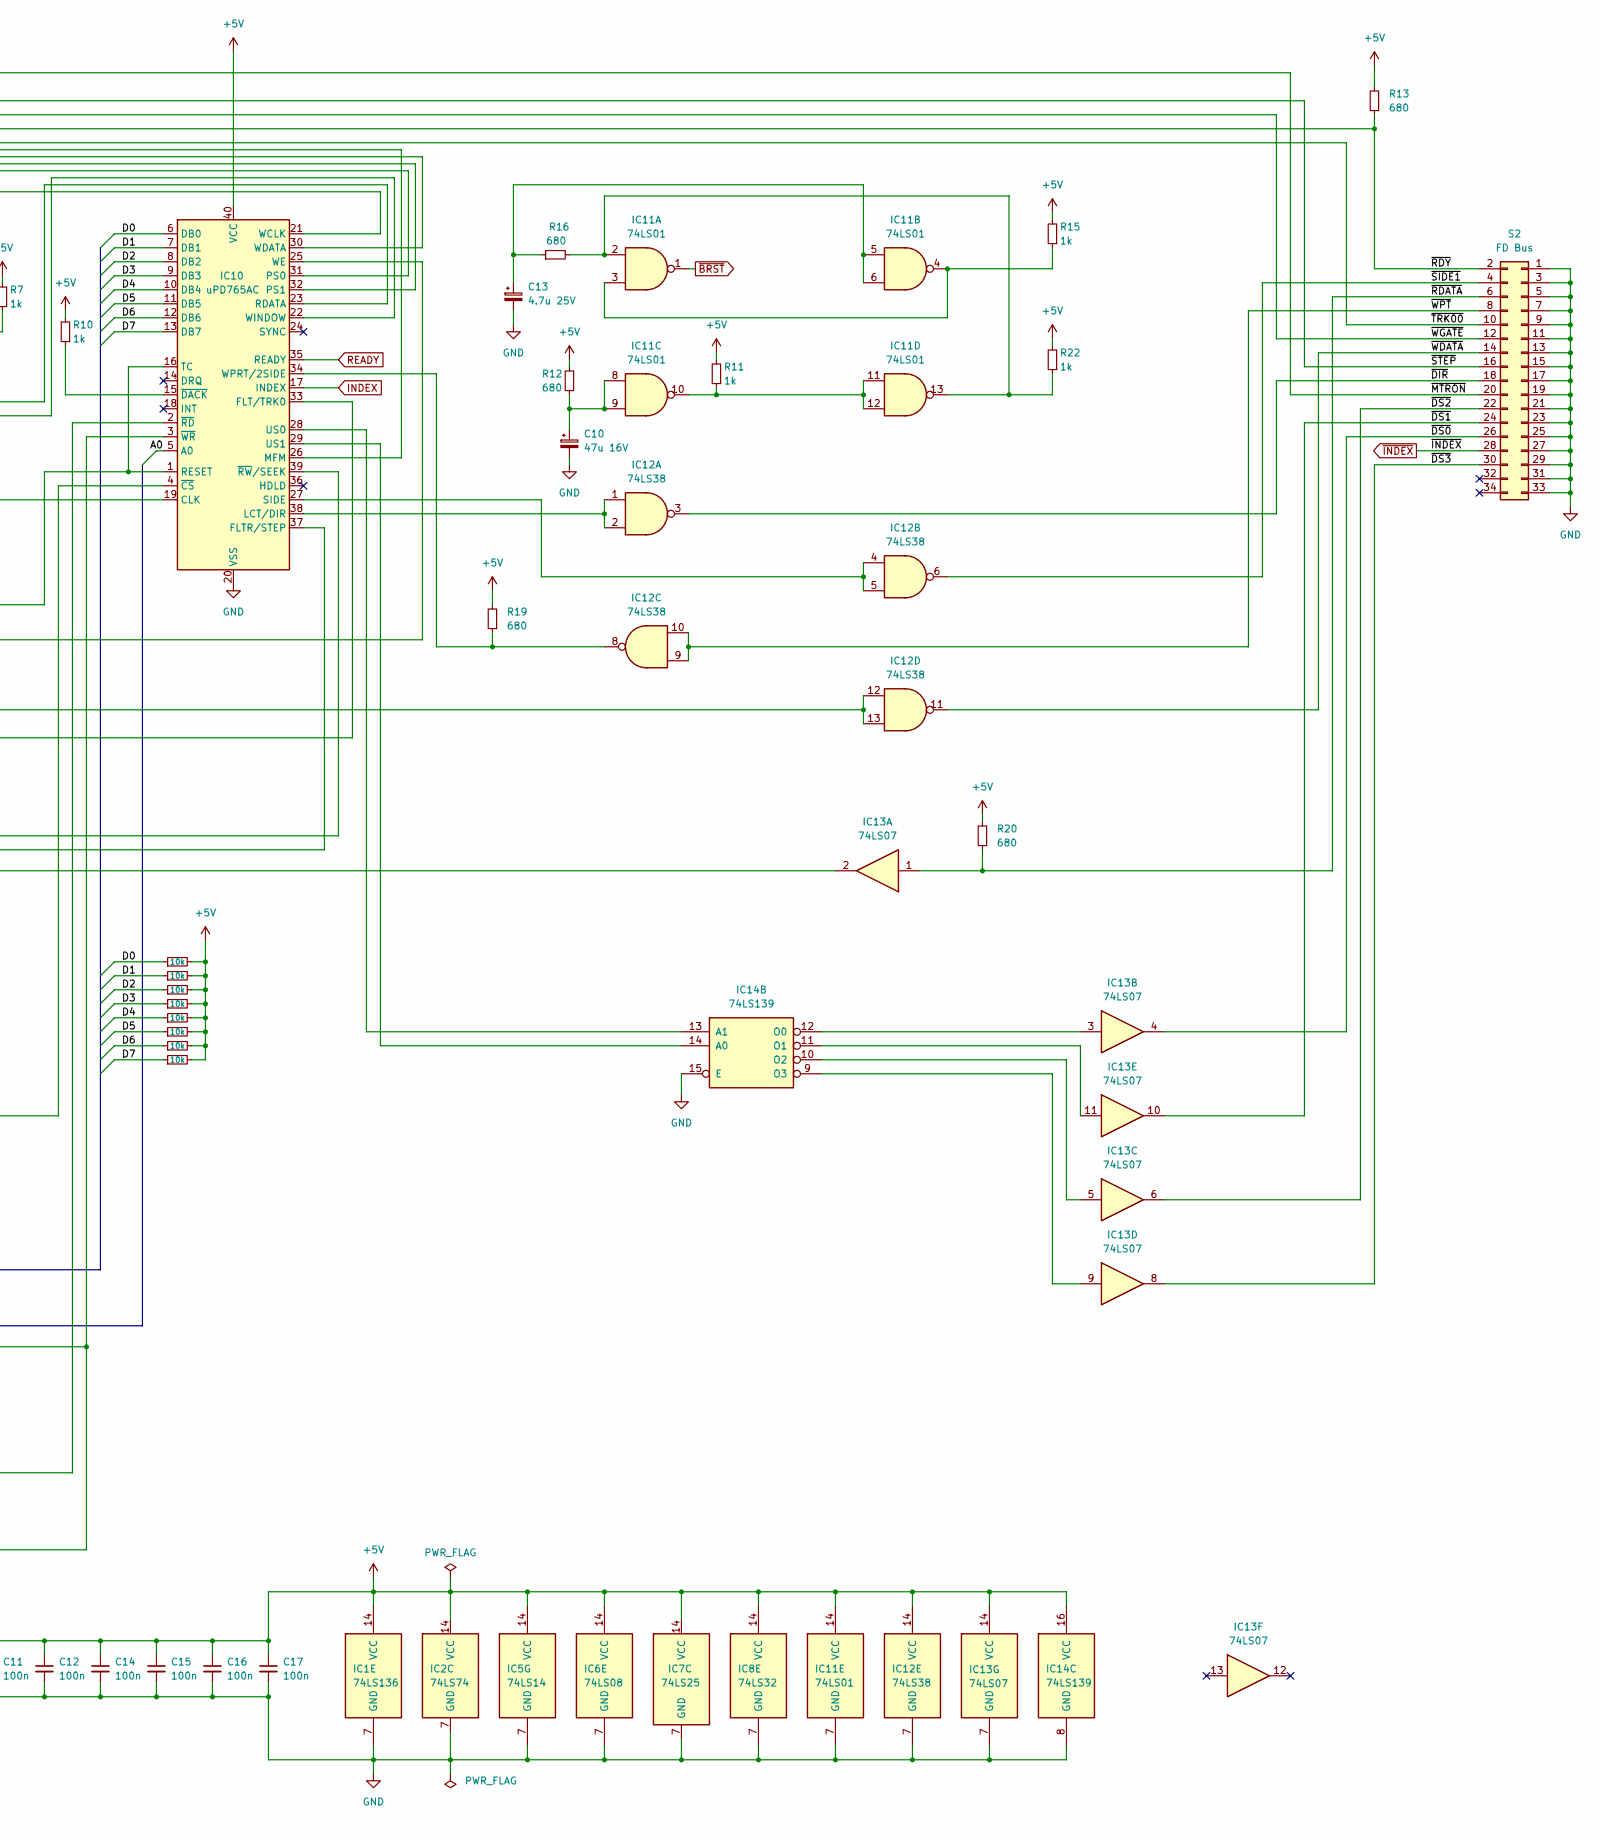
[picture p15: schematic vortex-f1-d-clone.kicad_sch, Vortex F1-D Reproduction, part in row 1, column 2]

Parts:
C1, C2, C3, C4, C6, C7, C8, C9, C11, C12, C14, C15, C16, C17: 100n; C_0603_1608Metric_Pad1.08x0.95mm_HandSolder
C5: 47p; C_0603_1608Metric_Pad1.08x0.95mm_HandSolder
C10: 47u 16V; C_0805_2012Metric_Pad1.18x1.45mm_HandSolder
C13: 4.7u 25V; C_0805_2012Metric_Pad1.18x1.45mm_HandSolder
D1: 1N4148; D_DO-35_SOD27_P7.62mm_Horizontal
IC1: 74LS136; DIP-14_W7.62mm_Socket
IC2: 74LS74; DIP-14_W7.62mm_Socket
IC3: 74LS85; DIP-16_W7.62mm_Socket
IC4: 27128; DIP-28_W15.24mm
IC5: 74LS14; DIP-14_W7.62mm_Socket
IC6: 74LS08; DIP-14_W7.62mm_Socket
IC7: 74LS25; DIP-14_W7.62mm_Socket
IC8: 74LS32; DIP-14_W7.62mm_Socket
IC9: FDC_9229; DIP-20_W7.62mm_Socket
IC10: uPD765AC; DIP-40_W15.24mm_Socket
IC11: 74LS01; DIP-14_W7.62mm_Socket
IC12: 74LS38; DIP-14_W7.62mm_Socket
IC13: 74LS07; DIP-14_W7.62mm_Socket
IC14: 74LS139; DIP-16_W7.62mm_Socket
R1, R2, R3, R4, R5, R9, R12, R13, R16, R19, R20: 680; R_0603_1608Metric_Pad0.98x0.95mm_HandSolder
R6, R7, R10, R11, R15, R21, R22: 1k; R_0603_1608Metric_Pad0.98x0.95mm_HandSolder
R8, R14, R17, R18, R23, R24, R25, R26: 10k; R_0603_1608Metric_Pad0.98x0.95mm_HandSolder
S1: CPC Bus; PinHeader_2x25_P2.54mm_Vertical
S2: FD Bus; IDC-Header_2x17_P2.54mm_Vertical

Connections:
+5V: C1.1, C2.1, C3.1, C4.1, C6.1, C7.1, C8.1, C9.1, C11.1, C12.1, C14.1, C15.1, C16.1, C17.1, IC1.1, IC1.10, IC1.13, IC1.14 (VCC), IC2.14 (VCC), IC3.4 (Ia>b), IC3.10 (A0), IC3.12 (A1), IC3.13 (A2), IC3.16 (VCC), IC4.1 (VPP), IC4.27 (~PGM), IC4.28 (VCC), IC5.14 (VCC), IC6.14 (VCC), IC7.3, IC7.11, IC7.14 (VCC), IC8.14 (VCC), IC9.2 (FDCSEL), IC9.16 (~TEST), IC9.20 (VCC), IC10.40 (VCC), IC11.14 (VCC), IC12.14 (VCC), IC13.14 (VCC), IC14.16 (VCC), R1.2, R2.2, R5.2, R6.2, R7.2, R8.2, R9.2, R10.2, R11.2, R12.2, R13.2, R14.2, R15.2, R17.2, R18.2, R19.2, R20.2, R21.2, R22.2, R23.2, R24.2, R25.2, R26.2, S1.27
/A0: IC4.10 (A0), IC10.5 (A0), S1.18
/A1: IC4.9 (A1), S1.17
/A2: IC4.8 (A2), S1.16
/A3: IC4.7 (A3), S1.15
/A4: IC4.6 (A4), S1.14
/A5: IC4.5 (A5), S1.13
/A6: IC4.4 (A6), S1.12
/A7: IC4.3 (A7), IC7.10, IC14.1 (E), S1.11
/A8: IC4.25 (A8), IC7.9, IC14.2 (A0), S1.10
/A9: IC4.24 (A9), S1.9
/A10: IC4.21 (A10), IC7.12, IC14.3 (A1), S1.8
/A11: IC4.23 (A11), S1.7
/A12: IC4.2 (A12), S1.6
/A13: IC4.26 (A13), IC8.10, S1.5
/A14: S1.4
/A15: IC6.2, S1.3
/CURSOR: S1.46
/D0: IC2.12 (D), IC3.14 (B2), IC4.11 (D0), IC10.6 (DB0), R8.1, S1.26
/D1: IC3.11 (B1), IC4.12 (D1), IC10.7 (DB1), R14.1, S1.25
/D2: IC3.9 (B0), IC4.13 (D2), IC10.8 (DB2), R17.1, S1.24
/D3: IC3.1 (B3), IC4.15 (D3), IC10.9 (DB3), R18.1, S1.23
/D4: IC4.16 (D4), IC7.5, IC10.10 (DB4), R23.1, S1.22
/D5: IC4.17 (D5), IC7.4, IC10.11 (DB5), R24.1, S1.21
/D6: IC4.18 (D6), IC7.2, IC10.12 (DB6), R25.1, S1.20
/D7: IC4.19 (D7), IC7.1, IC10.13 (DB7), R26.1, S1.19
/LPEN: S1.47
/RAMDIS: S1.45
/Sound: S1.1
/TRK00: IC5.10, IC6.5
/~BUSAK: S1.38
/~BUSRQ: S1.37
/~DIR: IC12.3, S2.18
/~DS0: IC13.4, S2.26
/~DS1: IC13.10, S2.24
/~DS2: IC13.6, S2.22
/~DS3: IC13.8, S2.30
/~EXP: S1.48
/~HALT: S1.34
/~INT: S1.35
/~IORQ: IC8.1, IC8.13, S1.31
/~M1: S1.29
/~MREQ: S1.28
/~MTRON: IC1.3, S2.20
/~NMI: S1.36
/~RDATA: IC13.1, R20.1, S2.6
/~RDY: IC5.9, R13.1, S2.2
/~RFSH: S1.30
/~SIDE1: IC12.6, S2.4
/~STEP: IC1.8, S2.16
/~TRK00: IC5.11, R1.1, S2.10
/~WDATA: IC12.11, S2.14
/~WGATE: IC1.11, S2.12
/~WPT: IC12.9, IC12.10, S2.8
/~WR: IC8.12, S1.33
CLK4: IC8.4, IC8.5, S1.50
GND: C1.2, C2.2, C3.2, C4.2, C5.2, C6.2, C7.2, C8.2, C9.2, C10.2, C11.2, C12.2, C13.2, C14.2, C15.2, C16.2, C17.2, IC1.7 (GND), IC2.7 (GND), IC3.2 (Ia<b), IC3.8 (GND), IC3.15 (A3), IC4.14 (GND), IC5.7 (GND), IC6.7 (GND), IC7.7 (GND), IC8.7 (GND), IC9.3 (MINI), IC9.10 (GND), IC9.19 (P2), IC10.20 (VSS), IC11.7 (GND), IC12.7 (GND), IC13.7 (GND), IC14.8 (GND), IC14.15 (E), R3.1, S1.2, S1.49, S2.1, S2.3, S2.5, S2.7, S2.9, S2.11, S2.13, S2.15, S2.17, S2.19, S2.21, S2.23, S2.25, S2.27, S2.29, S2.31, S2.33
INDEX: IC5.12, IC10.17 (INDEX)
unnamed: C5.1, IC5.3, R3.2, R4.1
unnamed: C10.1, IC11.8, IC11.9, R12.1
unnamed: C13.1, IC11.5, IC11.6, R16.1
unnamed: D1.2 (A), IC5.1, IC6.3
unnamed: IC1.2, IC2.9 (Q)
unnamed: IC1.4, IC8.6, R4.2, R5.1
unnamed: IC1.5, IC5.4
unnamed: IC1.6, IC9.11 (~CLKIN), R2.1
unnamed: IC1.9, IC6.11
unnamed: IC1.12, IC6.8
unnamed: IC2.2 (D), IC3.6 (Oa=b)
unnamed: IC2.3 (C), IC8.8
unnamed: IC2.5 (Q), IC6.1
unnamed: IC2.4 (~S), IC2.10 (~S), R21.1
unnamed: IC2.11 (C), IC7.8
unnamed: IC3.3 (Ia=b), IC7.6
unnamed: IC5.6, IC10.1 (RESET), IC10.16 (TC)
unnamed: IC6.6, IC10.33 (FLT/TRK0)
unnamed: IC6.9, IC10.25 (WE)
unnamed: IC6.12, IC10.37 (FLTR/STEP)
unnamed: IC6.4, IC6.13, IC10.39 (~RW/SEEK)
unnamed: IC7.13, IC8.9, IC8.11, IC10.3 (~WR)
unnamed: IC8.3, IC10.2 (~RD)
unnamed: IC9.1 (DSKD), IC13.2, R9.1
unnamed: IC9.4 (DENS), IC10.26 (MFM)
unnamed: IC9.5 (SEPCLK), IC10.22 (WINDOW)
unnamed: IC9.6 (SEPD), IC10.23 (RDATA)
unnamed: IC9.7 (WDOUT), IC12.12, IC12.13
unnamed: IC9.8 (HLT/CLK), IC10.19 (CLK)
unnamed: IC9.9 (CLKOUT), IC10.21 (WCLK)
unnamed: IC9.12 (WDIN), IC10.30 (WDATA)
unnamed: IC9.13 (EARLY), IC10.32 (PS1)
unnamed: IC9.14 (LATE), IC10.31 (PS0)
unnamed: IC9.17 (P0), R7.1
unnamed: IC9.18 (P1), R6.1
unnamed: IC10.4 (~CS), IC14.5 (O1)
unnamed: IC10.15 (~DACK), R10.1
unnamed: IC10.27 (SIDE), IC12.4, IC12.5
unnamed: IC10.28 (US0), IC14.13 (A1)
unnamed: IC10.29 (US1), IC14.14 (A0)
unnamed: IC10.34 (WPRT/2SIDE), IC12.8, R19.1
unnamed: IC10.38 (LCT/DIR), IC12.1, IC12.2
unnamed: IC11.3, IC11.4, R15.1
unnamed: IC11.10, IC11.11, IC11.12, R11.1
unnamed: IC11.2, IC11.13, R16.2, R22.1
unnamed: IC13.3, IC14.12 (O0)
unnamed: IC13.5, IC14.10 (O2)
unnamed: IC13.9, IC14.9 (O3)
unnamed: IC13.11, IC14.11 (O1)
READY: IC5.8, IC6.10, IC10.35 (READY), S1.39
ROMDIS: D1.1 (K), S1.43
~BRST: IC11.1, S1.40
~INDEX: IC5.13, S2.28
~RD: IC8.2, S1.32
~ROMEN: IC4.20 (~CE), S1.42
~ROMOE: IC4.22 (~OE), IC5.2

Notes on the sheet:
Motor
ROM Select

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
Board: 2 copper layers, 60 parts (0 on the bottom side), 101 nets, no tracks yet.

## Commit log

2022-07-14 First version passing ERC
    [vortex-f1-d-clone.kicad_pcb, vortex-f1-d-clone.kicad_sch]
2022-07-14 Slightly rearrange to fit on smaller paper
    [vortex-f1-d-clone.kicad_sch]
2022-07-14 Start placing components
    [vortex-f1-d-clone.kicad_pcb]
2022-07-14 PCB work
    [vortex-f1-d-clone.kicad_pcb, vortex-f1-d-clone.kicad_sch]
2022-07-17 ROMless variant schematic, CPC Dandanator CPLD
    [vortex-f1-d-no-rom.kicad_sch]
2022-07-31 routed no-rom board
    [vortex-f1-d-no-rom.kicad_pcb, vortex-f1-d-no-rom.kicad_sch]
2022-08-01 Silkscreen work
    [vortex-f1-d-no-rom.kicad_pcb]
2022-08-01 Unround corners
    [vortex-f1-d-no-rom.kicad_pcb]
2022-08-03 CPLD version PCB
    [vortex-f1-d-no-rom-cpld.kicad_pcb, vortex-f1-d-no-rom-cpld.kicad_sch]
2022-08-03 First cut at implementing CPLD logic
2022-08-04 Version with ROM
    [vortex-f1-d-cpld.kicad_pcb, vortex-f1-d-cpld.kicad_sch]
2022-08-07 Layout with ROM redone
    [vortex-f1-d-clone.kicad_sch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]
2022-08-09 sent TTL variant to aisler for production
    [vortex-f1-d-clone.kicad_sch, vortex-f1-d-no-rom.kicad_pcb, vortex-f1-d-no-rom.kicad_sch]
2022-08-09 Update version number
    [vortex-f1-d-no-rom.kicad_pcb]
2022-12-03 reorganize and fix no-rom pcb and schematic
    [vortex-f1-d-clone.kicad_pcb, vortex-f1-d-clone.kicad_sch, vortex-f1-d-no-rom.kicad_pcb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]
2022-12-03 re-fill zones
    [vortex-f1-d-no-rom.kicad_pcb]
2022-12-12 Save work
    [vortex-f1-d-no-rom.kicad_pcb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]
2023-01-04 Save CPLD work
    [vortex-f1-d-cpld.kicad_pcb, vortex-f1-d-cpld.kicad_sch]
2024-04-09 v1.0 sent to jlcpcb for production
    [vortex-f1-d-no-rom.kicad_pcb, vortex-f1-d-no-rom.kicad_sch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]
2024-04-12 cpl wip
    [vortex-f1-d-cpld.kicad_pcb, vortex-f1-d-cpld.kicad_sch, vortex-f1-d-no-rom-cpld.kicad_pcb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]
2024-06-03 assign address selection to pin
2024-06-03 add address select jumper to schematics
    [vortex-f1-d-no-rom-cpld.kicad_sch]
